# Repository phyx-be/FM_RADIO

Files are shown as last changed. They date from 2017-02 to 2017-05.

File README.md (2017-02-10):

# FM_RADIO

A low cost, arduino compatible, stereo FM radio designed to be used easy in use for elder people. Rotating the rotary encoder wil increase or decrease the volume, pushing it wil enable of disable the radio. The station is pre-defined in software. The board does feature some expansion abilities. You could add more buttons to change stations. Or add an [SSD1306](https://www.adafruit.com/datasheets/SSD1306.pdf) based I²C display to have a nice user interface.

## Hardware Revision 00

The board is designed around the [ATMega 328p](www.atmel.com/devices/ATMEGA328P.aspx), the same microcontroller found on the Arduino Uno. The RRD-102 FM module is used as FM receiver and two NS4158 class D amplifiers are used to provide more than enought audio output. We added all the required components for a AR1019 FM receiver solution in case the RRD-102 would nog suffice.

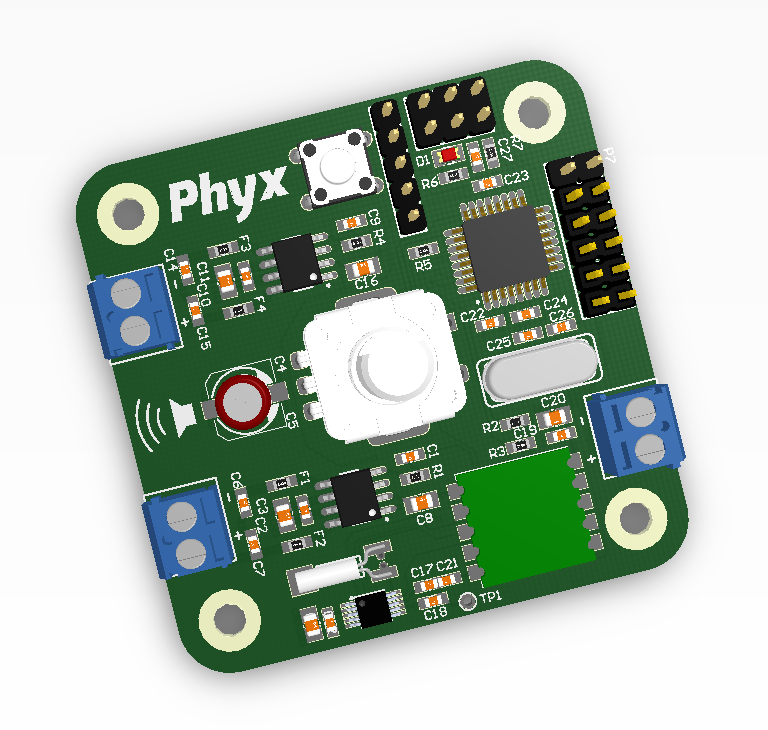
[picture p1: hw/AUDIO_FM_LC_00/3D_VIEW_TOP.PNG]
AUDIO_FM_LC_00_TOP

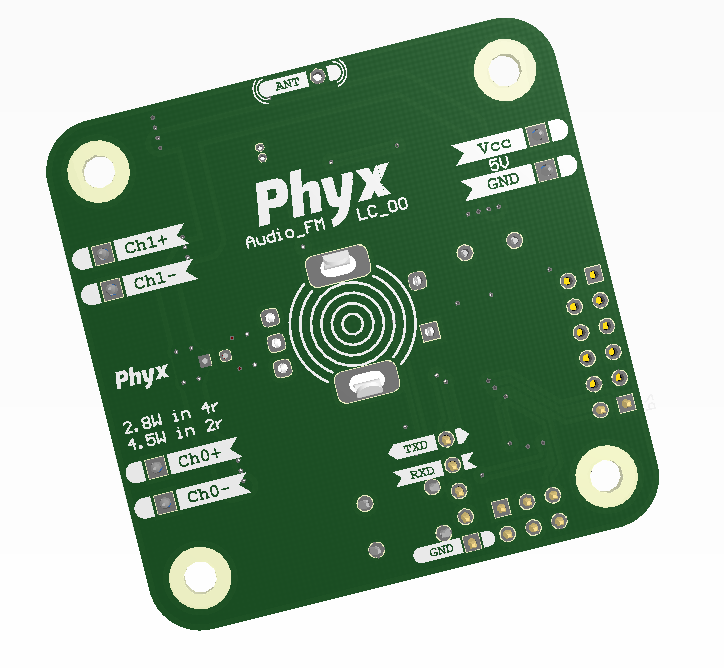
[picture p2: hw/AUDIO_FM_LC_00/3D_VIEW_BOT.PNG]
AUDIO_FM_LC_00_BOT


### Known issues

RRD-102 FM module should be powered by a 3.3V power supply, not 5V
The LED on the SCK pin will make it impossible to load new firmware through ISP

## Hardware Revision 01

We moved the power input to the same side as the speaker output, removed the AR1019 solution, added a 1117 voltage regulator for the 3.3V signals. Converted the I2C signals to 3.3V and added an easy-to-use header to add a small SSD1306 based OLED display.

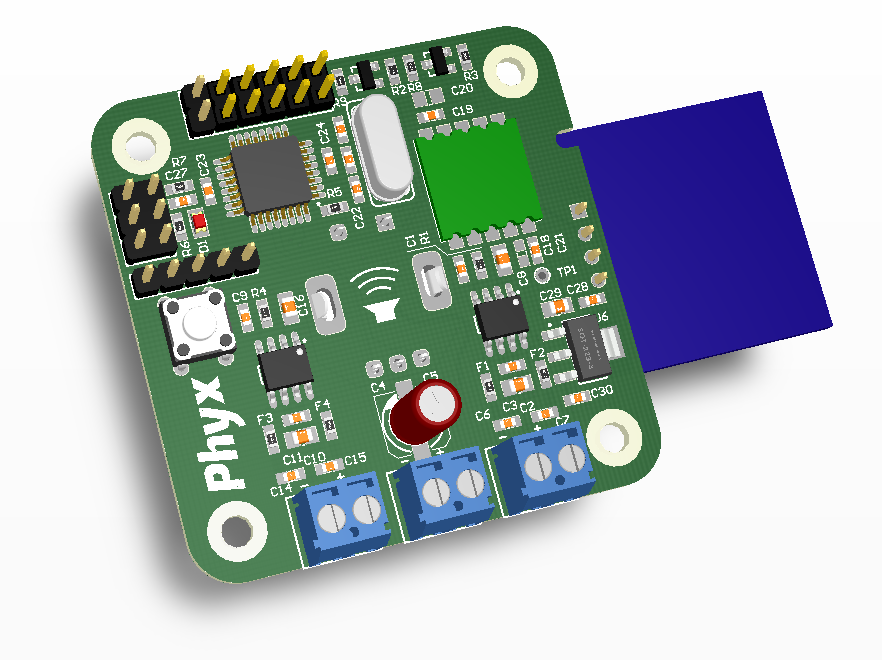
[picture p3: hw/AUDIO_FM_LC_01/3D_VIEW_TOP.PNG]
AUDIO_FM_LC_01_TOP

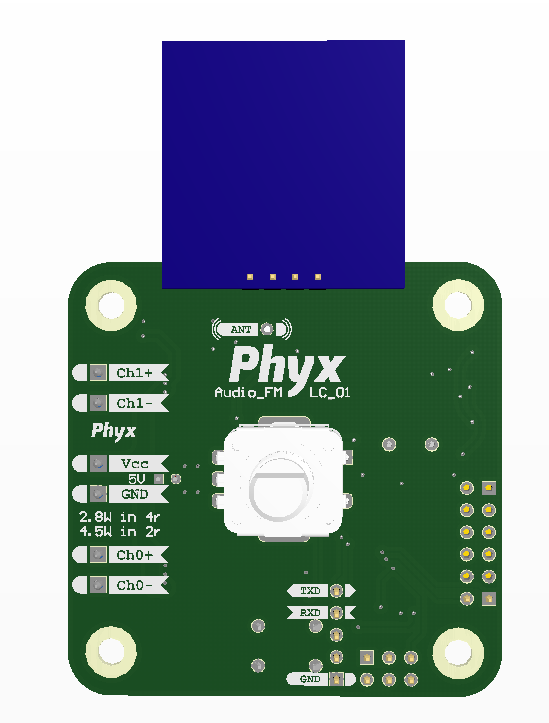
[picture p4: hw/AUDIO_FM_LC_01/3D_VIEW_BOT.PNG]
AUDIO_FM_LC_01_BOT


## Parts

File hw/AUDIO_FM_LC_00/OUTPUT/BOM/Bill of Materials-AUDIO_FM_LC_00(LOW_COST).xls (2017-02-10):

Bill of Materials |  |  | AUDIO_FM_LC
Project: |  | AUDIO_FM_LC_00.PrjPcb
Revision: |  | 00
Variant: |  | LOW_COST
Creation Date: | 5/01/2017 | 17:32:25
Print Date: | 2017-01-18 | 16:16:07
Footprint | Comment | LibRef | Designator | Value | Description | Supplier 1 | Supplier Part Number 1 | Quantity
C0603_N |  | CAP # 100nF 16V 0603 | C1, C3, C9, C11, C12, C19, C22, C23, C24, C27 | 100nF 16V | Capacitor Ceramic |  |  | 10
C0805_N |  | CAP # 10uF 6V3 0805 | C2, C10, C13, C20 | 10uF 6V3 | Capacitor Ceramic | Farnell | 2309029 | 4
C_5x11_2mm |  | CAP 100uF 10V 5x11mm | C5 | 100uF 10V | Capacitor electrolyt | Farnell | 1902882 | 1
C0603_N |  | CAP # 1nF 16V 0603 | C6, C7, C14, C15, C17, C18, C21 | 1nF 16V | Capacitor Ceramic |  |  | 7
C0805_N |  | CAP # 1uF 16V 0805 | C8, C16 | 1uF 16V | Capacitor Ceramic | Farnell | 2320853 | 2
C0603_N |  | CAP # 18pF 0603 | C25, C26 | 18pF | Capacitor Ceramic |  |  | 2
LED_0805_RD | Default 0805 Red LED | LED # Red 0805 | D1 |  |  | Farnell | 2099236 | 1
PEC11-4215F-S0024 | Rotary Encoder with Switch | ENC ROT INC 24-24ppr SW | ENC1 | PEC11-4215F-S0024 |  | Farnell |  | 1
L0603 | BLM18KG601SN1D | FER # 600R 1A3 0603 0R15 BLM18KG601SN1D | F1, F2, F3, F4 | 1A3 0R15 |  | Farnell | 1781094 | 4
WE_691103110002 | 2 Way Screw HDR 3,5mm | Terminal Block 3,5mm 2way - 691103110002 | P1, P3, P4 | 691103110002 |  | Wurth |  | 3
HDR2X3 | Header 3X2 | Pin Header 2.54mm dual row 6way | P2 |  |  |  |  | 1
HDR2X5 | Header 5x2 | Pin Header 2.54mm dual row 10way | P5 |  |  |  |  | 1
HDR1X5 | Header 5 | Pin Header 2.54mm 5way | P6 |  |  |  |  | 1
HDR1X2 | Header 2 | Pin Header 2.54mm 2way | P7 |  |  |  |  | 1
R0603_N |  | RES # 47K 0603 | R1, R4 | 47K |  |  |  | 2
R0603_N |  | RES # 1K 0603 | R2, R3 | 1K |  |  |  | 2
R0603_N |  | RES # 330R 0603 | R5, R6 | 330R |  | Farnell | 2446656 | 2
R0603_N |  | RES # 10K 0603 | R7 | 10K |  | Farnell | 2502397 | 1
TACTSW | Default TH TACT | SW TACT | SW1 |  |  |  |  | 1
SOIC_N_8_TH | 5W Class D mono amplifier inducter-less | AMP # AUDIO NS4158 | U1, U2 | NS4158 |  | Aliexpress | NS4158 | 2
TI_DGS_S-PDSO-G10 | FM Receiver I2C | FM # AR1019 | U3 | AR1019 |  | Aliexpress | AR1019 | 1
RRD-102 | RRD-102 V2.0 FM Radio Module With RDS decoding | FM # MOD RRD-102 | U4 | RRD-102 FM Module |  | Aliexpress | RRD-102 | 1
TQFP_32 | 8-bit MCU | AVR # ATMega 328 MCU TQFP | U5 | ATMega 328 | ATMega328 SMD TQFP |  |  | 1
CMR200T | 32.768Khz CMR200 12.5pF | XTAL # 32.768Khz 12.5pF CMR200 | Y1 | 32.768KHz | Crystal Oscillator | Farnell | 2101359 | 1
HC49US | 16MHz 18pF HC49US | XTAL 16Mhz HC49US | Y2 | 16MHz | Crystal Oscillator | Farnell | 2508458 | 1
 |  |  |  |  |  |  |  | 54
Approved |  | Notes

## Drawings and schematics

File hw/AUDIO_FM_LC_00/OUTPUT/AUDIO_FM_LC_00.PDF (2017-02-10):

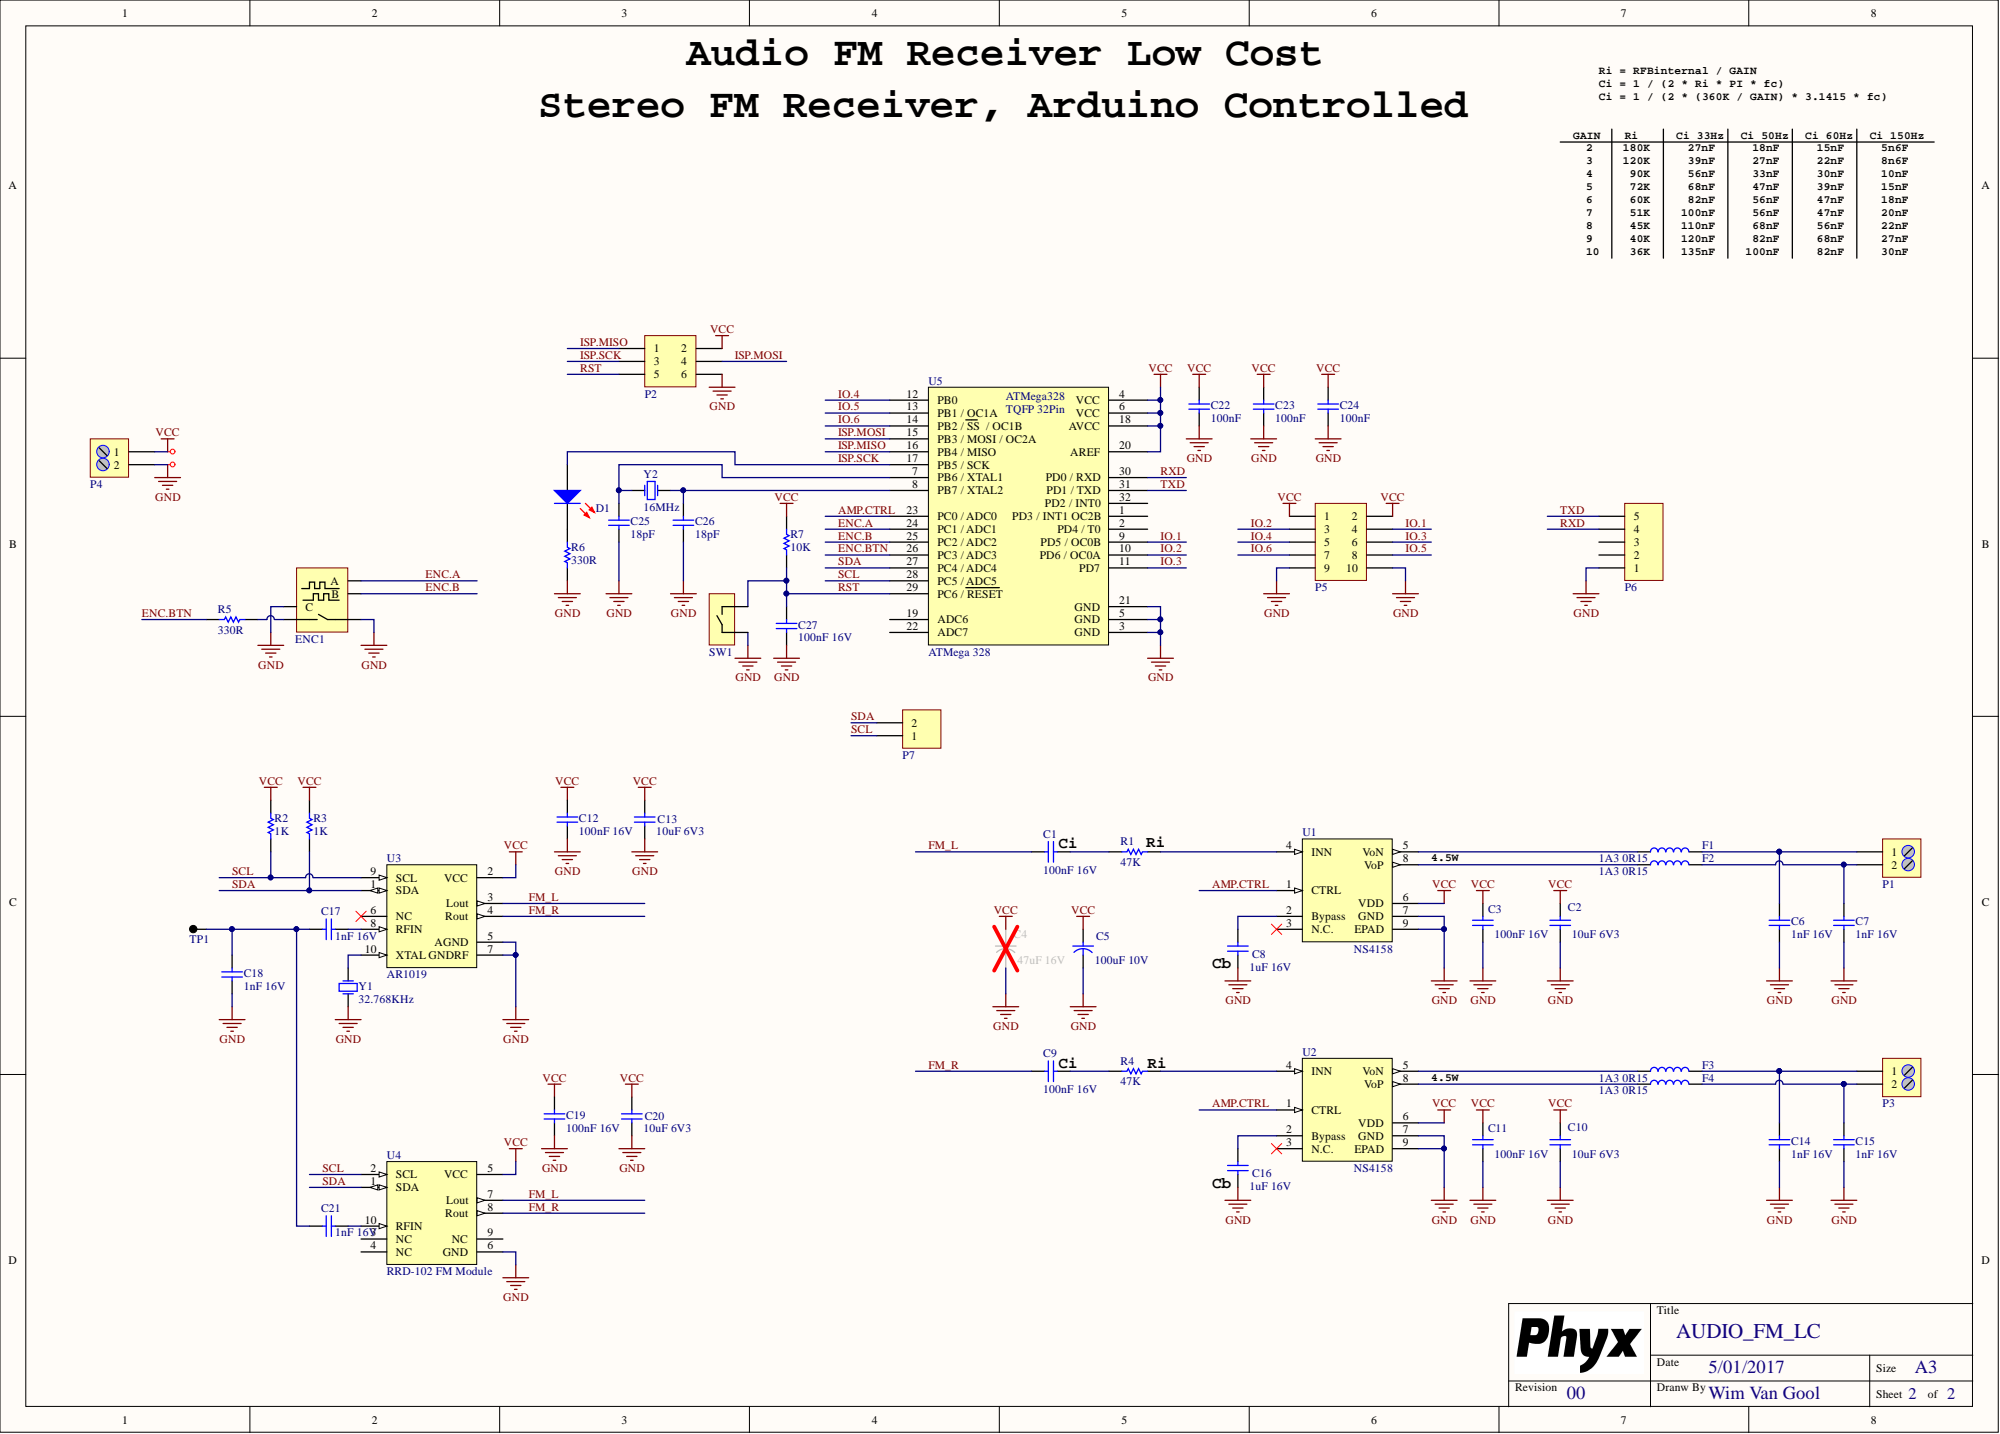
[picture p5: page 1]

Audio FM Receiver Low Cost

Ri = RFBinternal / GAIN

ISP.SCK | | PB5 / SCK 17

Y2 | | PB6 / XTAL1 7

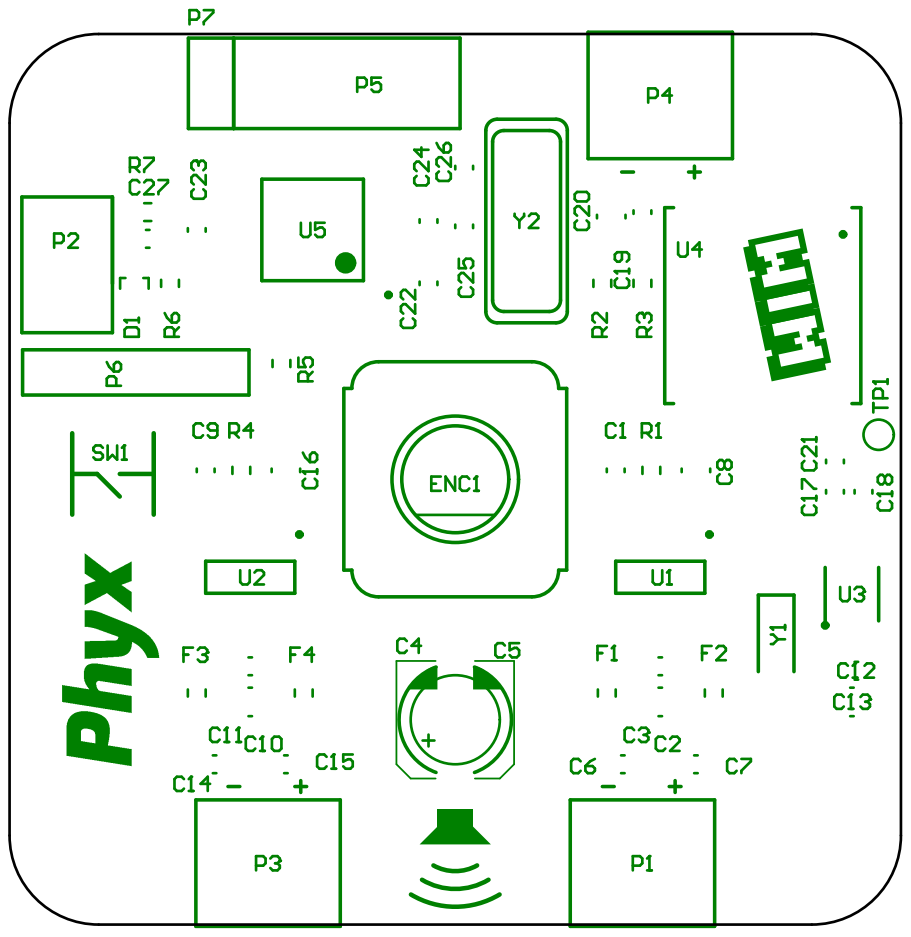
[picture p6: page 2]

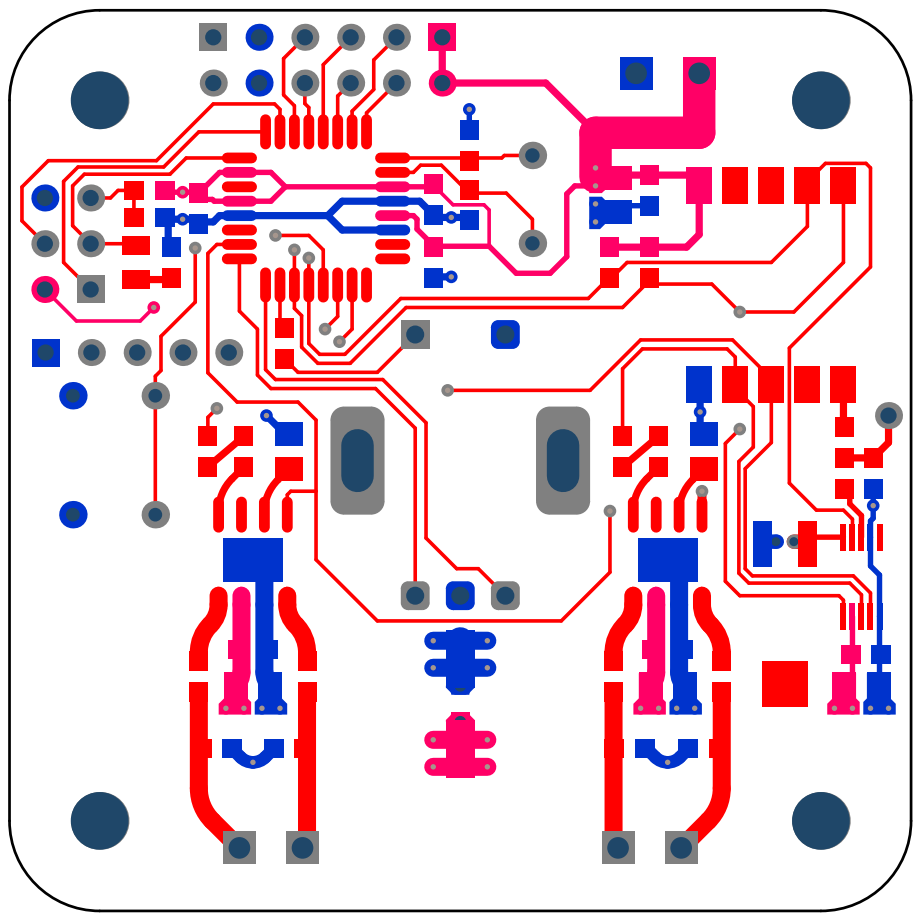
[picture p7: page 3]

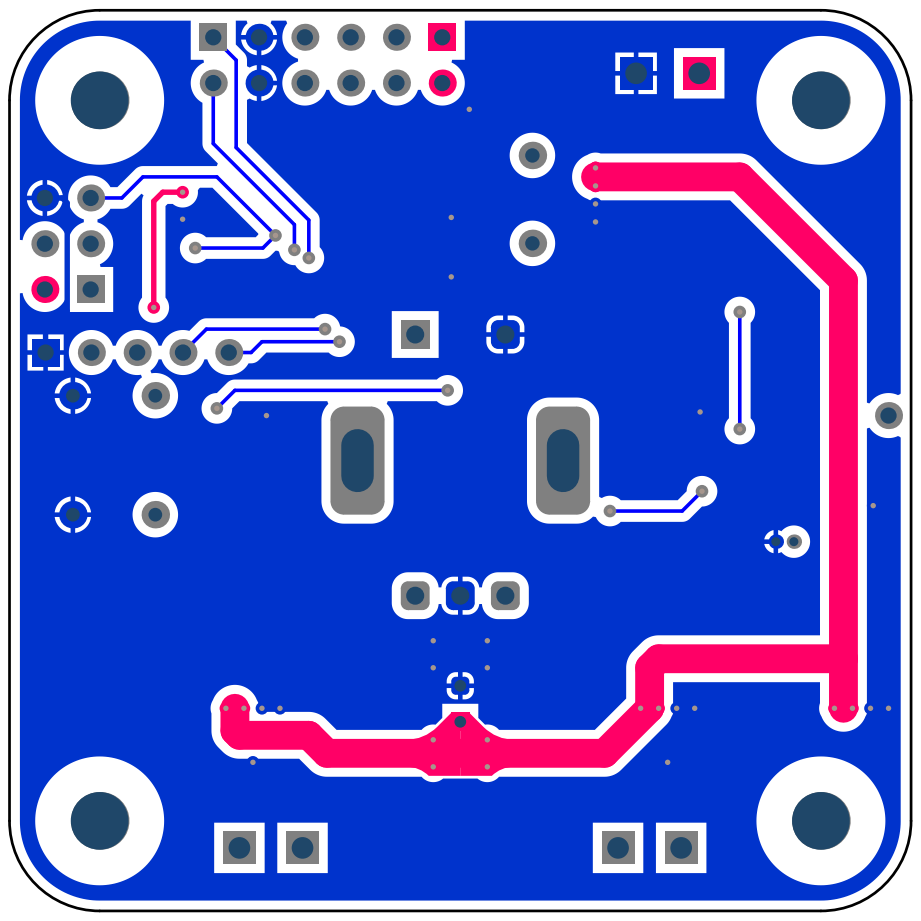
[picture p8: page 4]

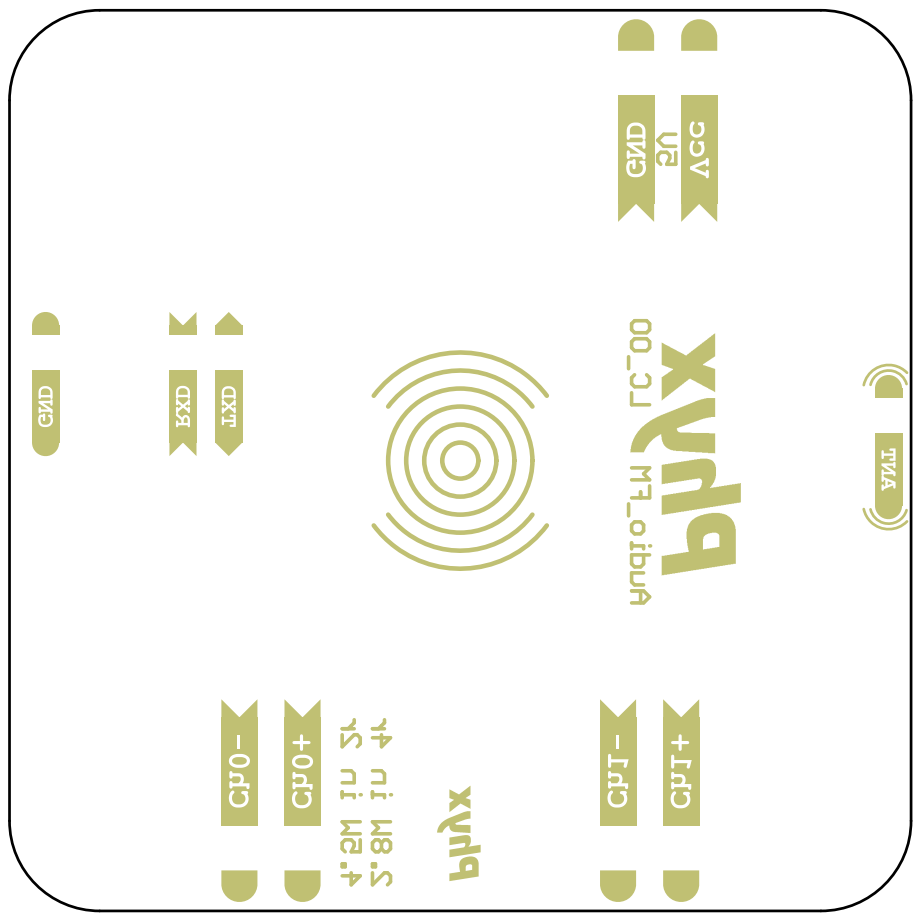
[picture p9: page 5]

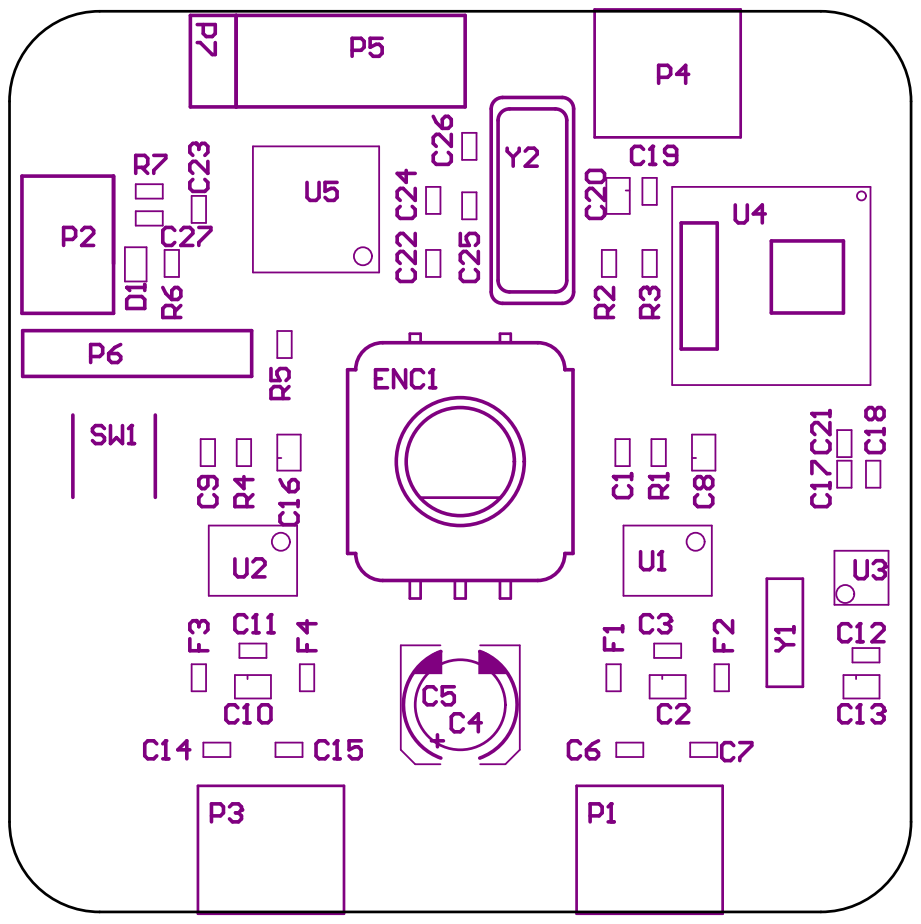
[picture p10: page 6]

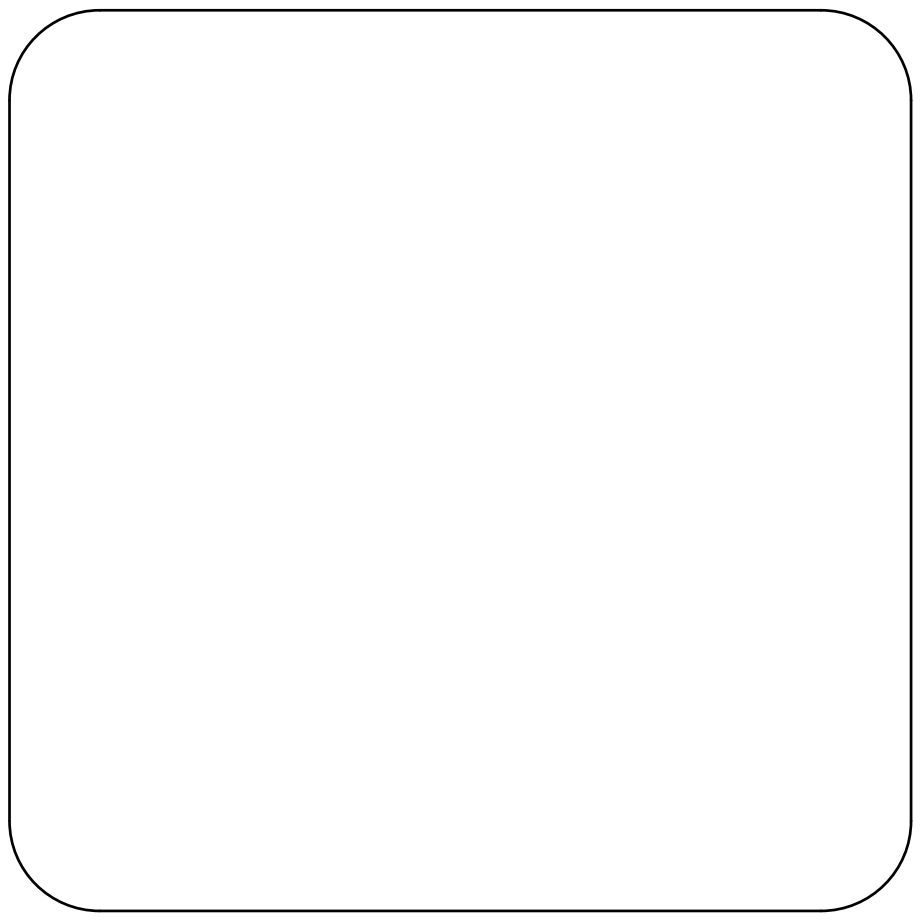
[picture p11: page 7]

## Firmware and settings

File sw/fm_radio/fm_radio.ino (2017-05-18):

/* 
 *  An Arduino sketch to operate a RDA5807M chip based radio using the Radio library of Matthias Hertel, http://www.mathertel.de.
 * This sketch implements a fixed radio station. The volume can be controlled using a rotary encoder.
 *
 * Bert Outtier
 * Copyright (c) 2017 by Bert Outtier.
 */

#include <Arduino.h>
#include <Wire.h>
#include <radio.h>
#include <RDA5807M.h>
#include <EEPROM.h>

// ID of the settings block
#define CONFIG_VERSION "fm1"

// Tell it where to store your config data in EEPROM
#define CONFIG_START 32

// Example settings structure
struct StoreStruct {
  // This is for mere detection if they are your settings
  char version[4];
  // The settings variables
  int encoder0Pos;        // encoder value (0 to VOLUME_LEVELS*PULSE_PER_VOLUME)
  int currentRadioState;  // is the radio on or off?
} storage = {
  CONFIG_VERSION,
  // The default values
  0,
  HIGH
};

// ----- Fixed settings -----
#define FIX_BAND          RADIO_BAND_FM   // The band that will be tuned by this sketch is FM.
#define FIX_STATION       8950            // The station that will be tuned by this sketch is 89.50 MHz = Klara
#define AMP_ENABLE_PIN    A1              // Amp enable pin (A1)
#define ENCODER_A         3               // Encoder pin A INT1
#define ENCODER_B         A2              // Encoder pin B (A2)
#define ENCODER_BUTTON    2               // Encoder button INT0
#define VOLUME_LEVELS     15              // Maximum number of volume levels
#define PULSE_PER_VOLUME  1               // pulses per volume up/down
#define LED_PIN           A0              // indicator LED pin (A0)     

int currentVolume;                 // current volume value    
int previousAmpState;              // previous amp state (enabled/disabled)
int currentAmpState;               // current amp state (enabled/disabled)
int previousButtonState = LOW;     // Previous encoder button state
int previousLongButtonState = LOW; // Previous long-press encoder button state
int currentButtonState = LOW;      // Current encoder button state
int previousRadioState;            // debounced previous button state (pressed/not pressed)
long time = 0;                     // the last time the encoder button pin was toggled
long debounce = 100;               // the debounce time
long longpress = 1000;             // long press time 1 sec

RDA5807M radio;    // Create an instance of Class for RDA5807M Chip

void buttonInterruptHandler()
{
  time = millis();
  currentButtonState = digitalRead(ENCODER_BUTTON);
}

void encoderInterruptHandler()
{
  if(digitalRead (ENCODER_A)) {
    if (digitalRead(ENCODER_B) == LOW) {
      if(storage.encoder0Pos > 0) storage.encoder0Pos--;
    } else {
      if(storage.encoder0Pos < (VOLUME_LEVELS*PULSE_PER_VOLUME)) storage.encoder0Pos++;
    }
  }
}

void loadConfig() {
  // To make sure there are settings, and they are YOURS!
  // If nothing is found it will use the default settings.
  if (EEPROM.read(CONFIG_START + 0) == CONFIG_VERSION[0] &&
      EEPROM.read(CONFIG_START + 1) == CONFIG_VERSION[1] &&
      EEPROM.read(CONFIG_START + 2) == CONFIG_VERSION[2]) {
    for (unsigned int t=0; t<sizeof(storage); t++) {
      *((char*)&storage + t) = EEPROM.read(CONFIG_START + t);
    }
  }
}

void saveConfig() {
  for (unsigned int t=0; t<sizeof(storage); t++) {
    EEPROM.write(CONFIG_START + t, *((char*)&storage + t));
  }
}

/// Setup a FM only radio configuration
/// with some debugging on the Serial port
void setup() {
  
  // open the Serial port
  Serial.begin(9600);
  Serial.println("Radio...");
  delay(200);

  //setup pins
  pinMode (AMP_ENABLE_PIN, OUTPUT);
  pinMode (LED_PIN, OUTPUT);
  pinMode (ENCODER_A,INPUT_PULLUP);
  pinMode (ENCODER_B,INPUT_PULLUP);
  pinMode (ENCODER_BUTTON,INPUT_PULLUP);

  // attach interrupts
  attachInterrupt(digitalPinToInterrupt(ENCODER_BUTTON), buttonInterruptHandler, CHANGE);
  attachInterrupt(digitalPinToInterrupt(ENCODER_A), encoderInterruptHandler, CHANGE);

  // load the settings
  loadConfig();

  // set volume to the saved setting
  currentVolume = storage.encoder0Pos/PULSE_PER_VOLUME;  
  if(storage.currentRadioState && currentVolume > 0){
    currentAmpState = HIGH;
  }
  else {
    currentAmpState = LOW;
  }
  previousAmpState = currentAmpState;
  previousRadioState = storage.currentRadioState;

  // set start state
  digitalWrite(AMP_ENABLE_PIN, currentAmpState); // enable amp
  digitalWrite(LED_PIN, currentAmpState); // enable led
  

  // Initialize the Radio 
  radio.init();

  // Enable information to the Serial port
//  radio.debugEnable();

  // Set all radio setting to the fixed values.
  radio.setBandFrequency(FIX_BAND, FIX_STATION);
  radio.setVolume(currentVolume);
  radio.setMono(false);
  radio.setMute(false);

  Serial.println("Init done!");
  
} // setup

void loop() {
//  char s[12];
//  radio.formatFrequency(s, sizeof(s));
//  Serial.print("Station:"); 
//  Serial.println(s);
//  
//  Serial.print("Radio:"); 
//  radio.debugRadioInfo();
//  
//  Serial.print("Audio:"); 
//  radio.debugAudioInfo();
  bool dirty = false;

  // Calculate the volume
  int newVolume = storage.encoder0Pos/PULSE_PER_VOLUME;
  if(newVolume != currentVolume) {
    currentVolume = newVolume;
    dirty = true;
    Serial.print("Set volume to ");
    Serial.println(currentVolume, DEC);
    radio.setVolume(currentVolume);
    if(currentVolume > 0) {
      currentAmpState = HIGH;
      storage.currentRadioState = HIGH;
    }
  }

  if (((millis() - time) > debounce) && (previousButtonState != currentButtonState)) {
    // whatever the reading is at, it's been there for longer
    // than the debounce delay, so take it as the actual current state:
    previousButtonState = currentButtonState;

    // Toggle on falling edge
    if (currentButtonState == LOW) {
      storage.currentRadioState = !storage.currentRadioState;
      Serial.print("Set radio state: ");
      Serial.println(storage.currentRadioState, DEC);
      dirty = true;
    }
  }

  if (((millis() - time) > longpress) && (previousLongButtonState != currentButtonState)) {
    // whatever the reading is at, it's been there for longer
    // than the debounce delay, so take it as the actual current state:
    previousLongButtonState = currentButtonState;

    // Toggle on rising edge
    if (currentButtonState == HIGH) {
      Serial.println("Long press");
    }
  }
  
  if(storage.currentRadioState && currentVolume > 0) {
    currentAmpState = HIGH;
  }
  else {
    currentAmpState = LOW;
  }

  if(previousAmpState != currentAmpState){
    Serial.print("Set amp: ");
    Serial.println(currentAmpState, DEC);
    digitalWrite(AMP_ENABLE_PIN, currentAmpState);
    digitalWrite(LED_PIN, currentAmpState);
    previousAmpState = currentAmpState;
  }

  if(dirty){
//    Serial.println("saving...");
    saveConfig();
//    Serial.println("save done!");
  }
} // loop

// End.
